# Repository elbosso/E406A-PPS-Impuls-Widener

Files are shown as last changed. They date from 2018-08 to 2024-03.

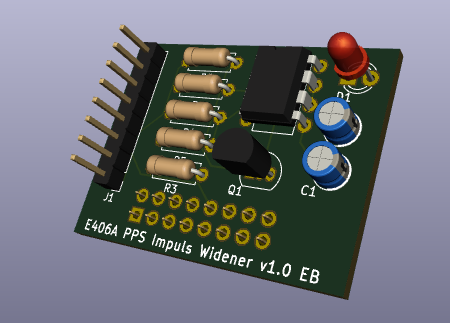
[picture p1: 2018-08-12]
front.png

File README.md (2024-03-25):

# E406A-PPS-Impuls-Widener

<!---
[![start with why](https://img.shields.io/badge/start%20with-why%3F-brightgreen.svg?style=flat)](http://www.ted.com/talks/simon_sinek_how_great_leaders_inspire_action)
--->










This is a project i needed for building my own stratum-0-NTP server using a Raspberry Pi: I used some components i had lying around - among them a SIRF III Receiver E406A. But to get a really accurate clock, one needs not only the GPS-Time but also the PPS Signal. This signal is provided by the E406A but the spike is way to short and its level is way to low for the raspberry to detect it on one of its GPIOs and in turn to trigger an interrupt.

So, i tried what i could with an NE555 - it detects the PPS and i used it to make it to last for approximately 0.3 seconds. The led really is only for people who like blinkenlights, the transistor is there because the NE555 starts with a falling sinal on trig - because the PPS from the E406A is rising I needed a simple inverter.

# Images of the PCB (images created automatically with GitHub actions provided by [kicad render action](https://github.com/linalinn/kicad-render?tab=readme-ov-file))

### Images
top
bottom

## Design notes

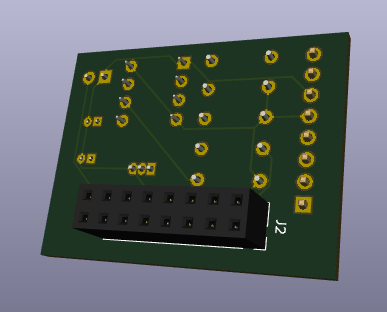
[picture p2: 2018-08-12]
back.png

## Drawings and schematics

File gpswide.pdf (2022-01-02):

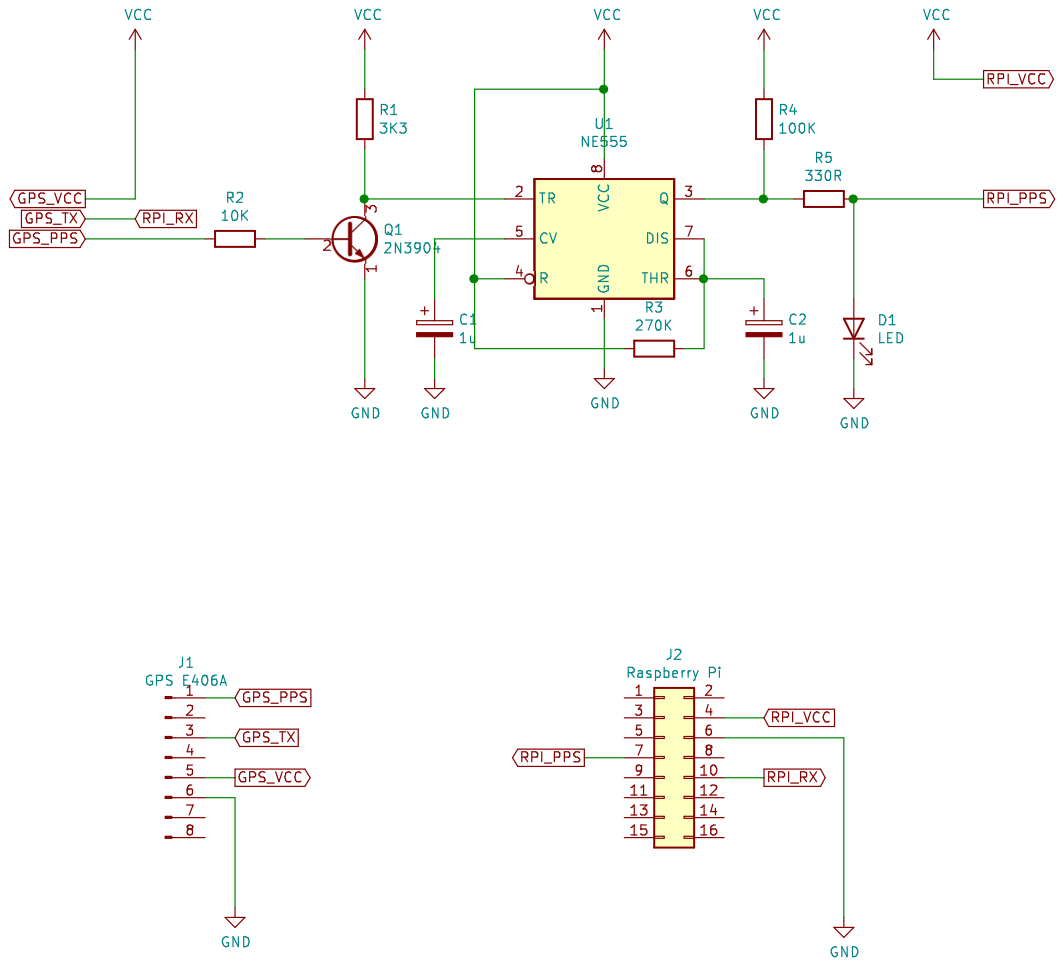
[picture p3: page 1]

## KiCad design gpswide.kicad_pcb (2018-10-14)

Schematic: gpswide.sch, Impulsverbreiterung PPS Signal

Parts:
C1, C2: 1u; CP_Radial_D4.0mm_P1.50mm
D1: LED; LED_D3.0mm
J1: GPS E406A; PinHeader_1x08_P2.54mm_Vertical
J2: Raspberry Pi; PinSocket_2x08_P2.54mm_Vertical
Q1: 2N3904; TO-92_Inline
R1: 3K3; R_Axial_DIN0207_L6.3mm_D2.5mm_P7.62mm_Horizontal
R2: 10K; R_Axial_DIN0207_L6.3mm_D2.5mm_P7.62mm_Horizontal
R3: 270K; R_Axial_DIN0207_L6.3mm_D2.5mm_P7.62mm_Horizontal
R4: 100K; R_Axial_DIN0207_L6.3mm_D2.5mm_P7.62mm_Horizontal
R5: 330R; R_Axial_DIN0207_L6.3mm_D2.5mm_P7.62mm_Horizontal
U1: NE555; DIP-8_W7.62mm

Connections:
GND: C1.2, C2.2, D1.1, J1.6, J2.6, Q1.1, U1.1 (GND)
GPS_PPS: J1.1, R2.2
GPS_TX: J1.3, J2.10
GPS_VCC: J1.5, J2.4, R1.1, R3.2, R4.1, U1.4 (R), U1.8 (VCC)
unnamed: C1.1, U1.5 (CV)
unnamed: C2.1, R3.1, U1.6 (THR), U1.7 (DIS)
unnamed: Q1.2, R2.1
unnamed: Q1.3, R1.2, U1.2 (TR)
unnamed: R4.2, R5.2, U1.3 (Q)
RPI_PPS: D1.2, J2.7, R5.1

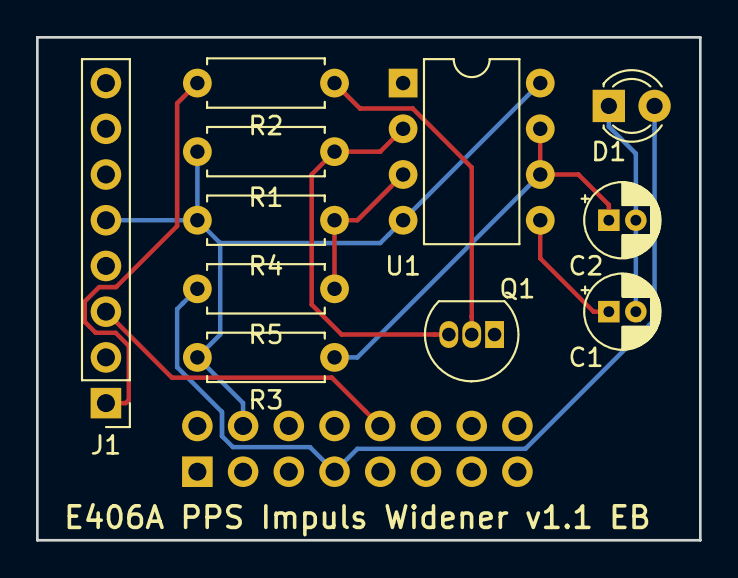
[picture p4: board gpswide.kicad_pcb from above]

Board: 2 copper layers, 36.8 x 27.9 mm, 12 parts (1 on the bottom side), 10 nets.

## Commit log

2018-08-12 Initial checkin
    [gpswide.kicad_pcb, gpswide.sch]
2018-08-12 cleaned up
    [gpswide.kicad_pcb, gpswide.sch]
2018-08-13 ground plane added
    [gpswide.kicad_pcb, gpswide.sch]
2018-10-14 v 1.1: Transistor footprint changed, resistor value changed
    [gpswide.kicad_pcb, gpswide.sch]
